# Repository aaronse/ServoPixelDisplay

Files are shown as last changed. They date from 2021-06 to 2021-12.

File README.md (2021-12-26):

  # Multiverse's Lowest LO-FI Wood Pixel Display—Arduino Art 
  Lowest LOFI display in the known 10 hyper dimensional multiverse, that I've seen.  Wood based tech art.
  
  Watch https://www.youtube.com/watch?v=4f1J5LzRdIo for usage and build information.
  
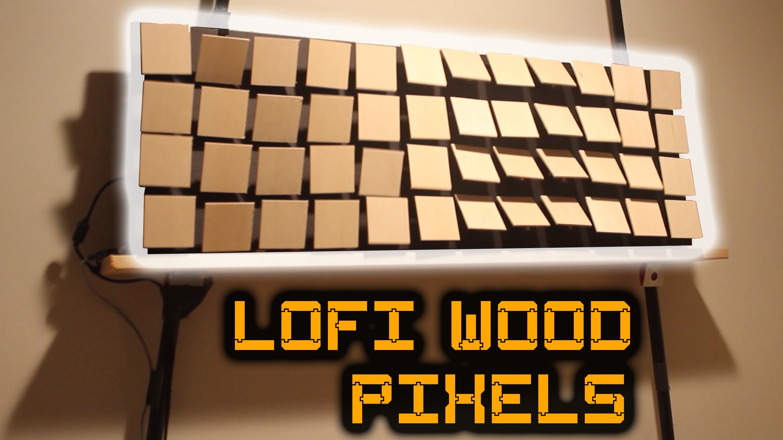
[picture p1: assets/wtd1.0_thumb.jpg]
  
  
  This code was written to power the WTD 1.0 (Wood Tile Display) project 
  created while participating in Mark Rober's 
  https://monthly.com/mark-rober-engineering course.

  Cheers!
  
  aaron (Aza's Built to Code)

  ## Code
  [src/wtd_1/wtd_1.ino](src/wtd_1/wtd_1.ino)
  - Displays Wave pattern by default.  Pause/Resume by sending "1" via Serial Monitor.  Edit _mode to change default start mode.

  ## Model .STL file
  [SG90 Arm Angle 10.stl](models/SG90%20Arm%20Angle%2010.stl)
  <!-- https://github.com/aaronse/ServoPixelDisplay/blob/main/models/SG90%20Arm%20Angle%2010.stl -->
  
  ## Build

  Backside view of the rats nest wiring.  Note the WAGO connectors, 16awg for power, and skinny wiring for data lines.  v1.0 was (under) powered by a 5v 5amp Alitov power adapter.
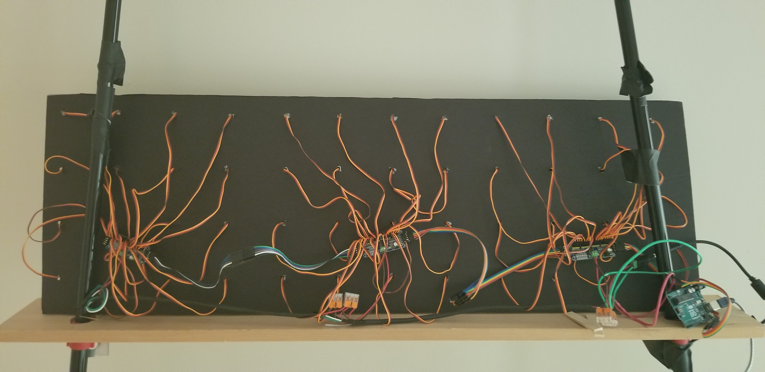
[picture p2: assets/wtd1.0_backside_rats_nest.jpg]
WTD v1.0 backside rats nest
  

  ## Related work/projects
  
- https://github.com/julienp17/WaveMirror (reco by https://github.com/scorto)
- "Reflection" - Making of an art installation for Prague Signal Festival, https://www.youtube.com/watch?v=jHo4l41cz8s

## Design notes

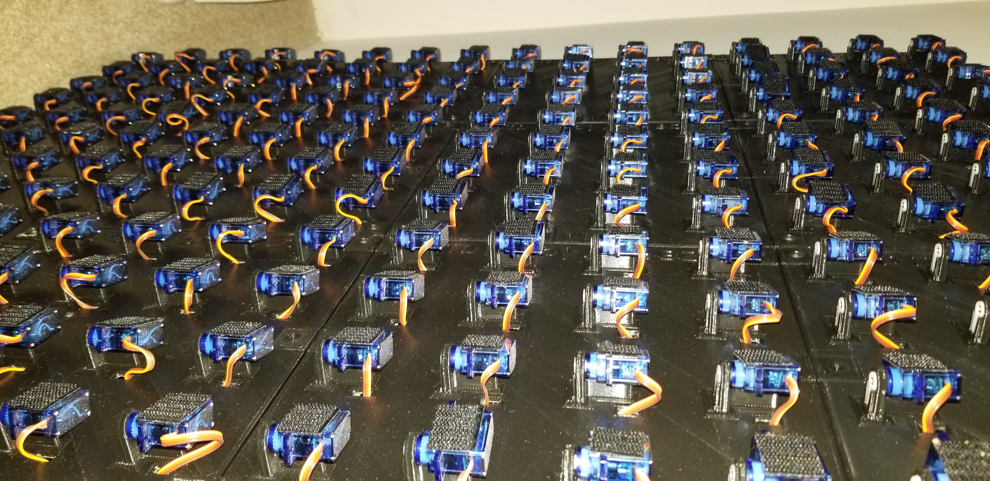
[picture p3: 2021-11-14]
assets/wtd2.0_servos_mounted.jpg

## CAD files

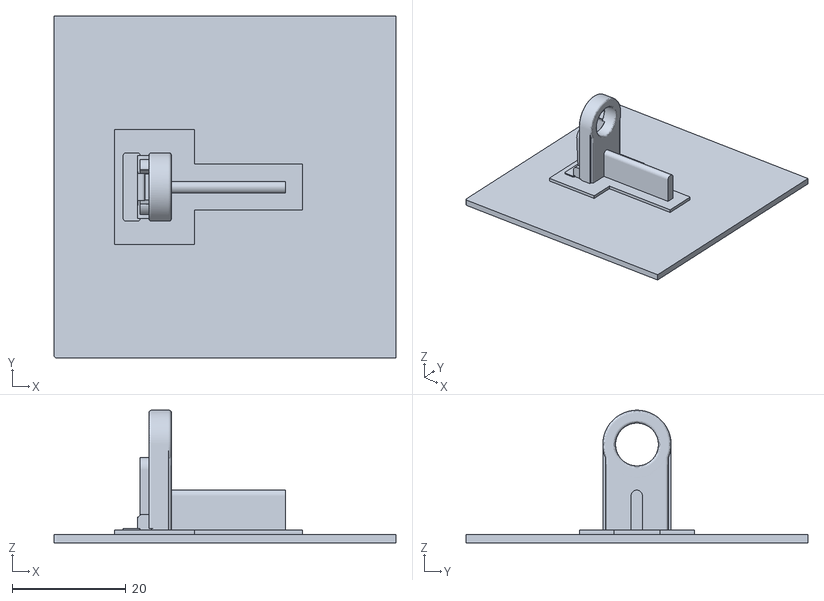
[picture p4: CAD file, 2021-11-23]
models/WTD_Tile_v2.1_60mm.stl
60.0 x 60.0 x 23.3

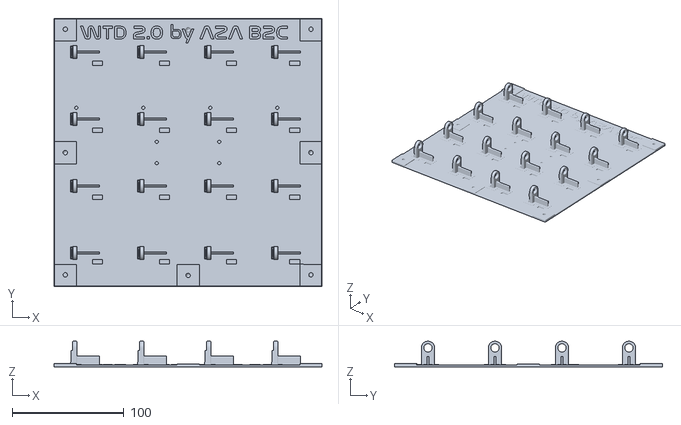
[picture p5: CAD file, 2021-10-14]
models/WTD_Tile_v2.7_4x4.stl
240.0 x 240.0 x 23.0

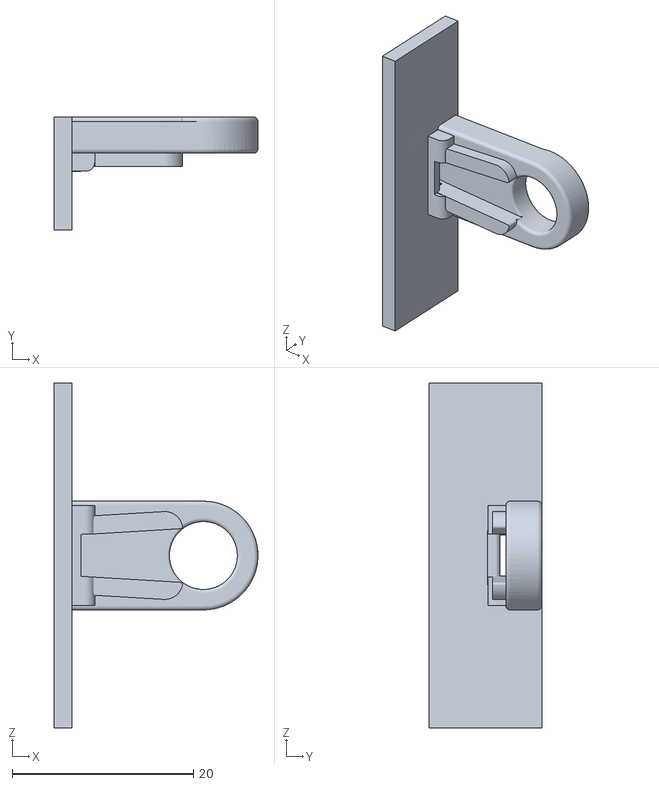
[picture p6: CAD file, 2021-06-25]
models/SG90 Arm Angle 10.stl
22.5 x 12.5 x 38.1

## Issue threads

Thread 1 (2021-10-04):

Hey this is Juan Sebastian from the YouTube comment. My partner and I are working on our senior capstone project that follows the same path as yours.

TigerKIN3, 2021-10-04:
We have our concerns about power draw due to us planning to use 320 servos. We are also concerned about the wire gauge for that many servos. There are more but we haven't explored them enough.

aaronse, 2021-10-04:
Hello @TigerKIN3, 320 servos, wow!   Haven't built anything that large, would love to hear from folks that have.  I know less about hardware/electrical than software.  Personally, would plan for 150ma per servo, but would expect steady state (servo not moving) will draw much less than 150ma.  So, 150ma X 320 = 48amp, I'd plan for 80% or less of supply capacity.  So 5v 60amp would be what I'd get, infact, https://www.amazon.com/gp/product/B00IWC2RLS is what I ended up buying for WTD 2.0.  Used mix of flexible silicone 14-18AWG wire (depending on expected current) for trunks going from power supply to each Pca9685 board.

TigerKIN3, 2021-10-04:
Thank you @aaronse for the insightful information. We plan on using SG-90 servos like the ones in your video. Is there any servos problems that we should look out for in our construction.

aaronse, 2021-10-04:
You're welcome.  Been pretty lucky with https://amzn.to/3oxd1E5, so far...  ~5% arrived broken/not-working.  Initially over ordered by 10% expecting some Duds, returning ones I didn't need...  Experienced some jittering/twitching by the servos when they're supposed to be steady, could be caused by bad/wrong wiring on my part.

*IF* you run into jitter issues, something to consider is using the PCA9685's OE pin to cut power via your code for moments when you're not expecting the Servo's to move.  Didn't do this, feel free to share pull request if you encounter and fix this issue :-)

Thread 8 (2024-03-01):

Servo Motors move jerkily, how to improve the movement?

aaronse, 2024-03-01:
hi, I tried your program but the servomotors move jerkily, what can I do to improve the movement of the motors? Furthermore, I would like to slow down the speed of the servomotors, what can I do?

_Originally posted by @Salvolongo in https://github.com/aaronse/ServoPixelDisplay/discussions/2#discussioncomment-8648347_

aaronse, 2024-03-01:
Hello @Salvolongo!

The issue you're encountering with jerky movements in SG90 9g servo motors, while using PCA9685 PWM servo controller boards, can stem from several factors. Here are common reasons and solutions to improve the movement of the motors:

### 1. Power Supply Issues
- **Problem:** Inadequate or unstable power supply can cause jerky movements. SG90 servos typically operate at 4.8V to 6V, and their performance can significantly degrade if the voltage drops below this range or if the power supply cannot provide sufficient current.
- **Solution:** Ensure your power supply can deliver consistent voltage within the servo's operating range and can handle the current draw of all servos under load. Using a dedicated, high-quality power supply might resolve the issue.

### 2. Signal Interference or Noise
- **Problem:** Electrical noise or interference in the PWM signal from the PCA9685 to the servos can cause erratic movements.
- **Solution:** Use shorter cables to reduce the chance of interference, and consider adding ferrite beads or capacitors to filter out noise. Ensuring solid, clean connections can also help.

### 3. PWM Frequency Mismatch
- **Problem:** The PCA9685 allows you to set the PWM frequency, and if this frequency doesn't match what the servos expect, it can result in jerky movements.
- **Solution:** The SG90 servos typically expect a 50Hz PWM signal. Ensure the PCA9685 is configured to output at this frequency.

### 4. Mechanical Load and Binding
- **Problem:** Mechanical resistance or binding in the servo gears or in the mechanism the servos are driving can cause jerky movements.
- **Solution:** Check for any mechanical issues that might be causing resistance to the servo's movement. Lubricate gears if necessary and ensure that the load on the servo is within its capabilities.

### 5. Software Issues
- **Problem:** The way the PWM signals are being modulated in your code can lead to jerky movements if not done smoothly.
- **Solution:** Implement smoother transitions in your control algorithm. For example, instead of jumping from one position to another instantly, gradually increase the PWM signal to create a smoother motion.

### 6. Servo Quality or Damage
- **Problem:** SG90 servos are inexpensive and can vary in quality. Sometimes, internal damage or wear can cause poor performance.
- **Solution:** Test with another servo to see if the problem persists. If a replacement servo works better, the issue might be with the original servo's quality or condition.

### 7. Calibration Issues
- **Problem:** If the PCA9685's PWM signal doesn't match the servo's expected pulse width for its range of motion, it can cause erratic behavior.
- **Solution:** Calibrate your system by adjusting the PWM signal's pulse width to ensure it aligns with the servo's specifications for minimum and maximum positions.

### Additional Tips:
- **Use External Power:** For multiple servos, it's often recommended to power the servos separately from the logic board to prevent voltage drops and interference.
- **Check for Overloading:** Ensure that the servos are not being overloaded beyond their torque capacity, as this can also cause jerky movements.
- **Update Firmware/Software:** Make sure that the firmware on the PCA9685 and your control software are up to date to benefit from any bug fixes or improvements.

By systematically addressing these potential issues, you should be able to identify and mitigate the cause of the jerky movements in your SG90 servo motors.

Can slow down speed of the servomotors by changing the delay(10); which means wait 10 milliseconds, to a much larger number between updates, maybe try 100 milliseconds, something to experiment with.

https://github.com/aaronse/ServoPixelDisplay/blob/5fcea9af71efd5064f86ff9575d3d690f0de3f88/src/wtd_1/wtd_1.ino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

Hope that helps.  Cheers!

aaronse, 2024-03-01:
Closing this as an issue, and following up in the Q&A /Discussion area instead https://github.com/aaronse/ServoPixelDisplay/discussions/9

Salvolongo, 2024-03-02:
I tried bringing the delay to 100, the motors move slower but they move jerkily and have a bad effect, I would like to make the movements more fluid, the motors are not attached to anything so they are not overloaded

Closed 2024-03-01.

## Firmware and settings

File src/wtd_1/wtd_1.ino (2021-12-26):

/******************************************************************************

  "Multiverse's Lowest LO-FI Wood Pixel Display—Arduino Art" (Version 1.0)
  https://www.youtube.com/watch?v=4f1J5LzRdIo

  This code was written to power the WTD 1.0 (Wood Tile Display) project 
  created while participating in Mark Rober's 
  https://monthly.com/mark-rober-engineering course.

  The code, originally written in a day, started out based on an AdaFruit 
  sample, and uses Adafruit's library for PCA9685 based 16-channel PWM & Servo 
  drivers.  Consider buying drivers and other hardware goodies from the 
  Adafruit shop @ http://www.adafruit.com/products/815
  
  Adafruit invests time and resources providing this open source code, 
  please support Adafruit and open-source hardware by purchasing 
  products from Adafruit!

  Cheers!

  aaron (Aza's Built to Code)
******************************************************************************/

#include <Wire.h>
#include <Adafruit_PWMServoDriver.h>

// Animation modes
#define MODE_NONE 0
#define MODE_WAVE 1
#define MODE_INVERT 2

// NOTE: EDIT FOR YOUR BUILD.
int _mode = MODE_WAVE; // Starts with WAVE mode, edit to MODE_NONE if you don't want WTD to be move until prompted.

// NOTE: EDIT FOR YOUR BUILD
// - Should be set to number of PCA9685 drivers used. Current code assumes each 
//   driver is connected to 16 servos. So, should define as total servo count 
//   divided by 16, e.g. 9 for 144 == 12x12 servo build.
#define DRIVER_COUNT 3

// NOTE: EDIT FOR YOUR BUILD
// - Short: Servo driver I2C Address definitions.
// - Long: pwmDrivers[] defines a list of PCA9685 servo drivers. Each PCA9685 
//   driver has a unique I2C address, starting at 0x40 (you solder during build
//   assembly). The code uses this list to figure out which PCA9685 servo 
//   driver is connected to a given servo, enabling the code to send commands 
//   to a specific driver. So, for example, with a 144 servo build, 9 entries 
//   would need to be defined, each entry with a unique I2C address based on
//   what was soldered during WTD assembly. See "Assumptions:" content to 
//   understand tileset layout and wiring sequence assumed by the code.
Adafruit_PWMServoDriver pwmDrivers[] =
{
   Adafruit_PWMServoDriver(0x40), // Ensure the address sequence here matches your Build's tileset layout.  Left to right, row by row, starting from top row.
   Adafruit_PWMServoDriver(0x41),
   Adafruit_PWMServoDriver(0x42)
};

// NOTE: EDIT FOR YOUR BUILD
#define CANVAS_WIDTH 12   // Servos per row, think of as display pixel width.
#define CANVAS_HEIGHT 4   // Number of rows, think of as display pixel height. 

// NOTE: *MAYBE* EDIT FOR YOUR BUILD, if you're not using Miuzei SG90 servos.
// - Depending on your servo make, the pulse width min and max may vary, you 
//   want these to be as small/large as possible without hitting the hard stop
//   for max range. You'll have to tweak them as necessary to match the servos
//   you have!  The following worked for my Miuzei SG90 servos.
#define SERVOMIN  150 // - This is the 'minimum' pulse length count (out of 4096)
#define SERVOMAX  600 // - This is the 'maximum' pulse length count (out of 4096)
#define SERVO_FREQ 60 // - Analog servos run at ~60 Hz updates.  Try 50 (original 
                      //   sample value) if your servos have a seizure using 60.

#define PIXEL_COUNT CANVAS_WIDTH * CANVAS_HEIGHT
#define TILESET_WIDTH 4   
#define TILESET_HEIGHT 4

#define MIN_SERVO_ANGLE 0
#define MAX_SERVO_ANGLE 60

// Menu variable to pick each menu item(or display the menu)
int _menu = -1;

// Flag indicating whether to move/animate
bool _isActive = true;

float _pixels[PIXEL_COUNT];
bool _pixelsDirty = true;
int _currentPixelIndex = 0;
unsigned long _lastChangeMs = 0;
unsigned long _invertWaitIntervalMs = 10;
unsigned long _waveWaitIntervalMs = 10;

void drawFill(int color);
void processMenu();
void processPixels();
void woodTilePanel_loop();


void setup() {
  Serial.begin(9600);
  Serial.println("setup");

  for (int i = 0; i < DRIVER_COUNT; i++) {
    pwmDrivers[i].begin();

  /* From AdaFruit sample code:
   * "In theory the internal oscillator (clock) is 25MHz but it really isn't
   * that precise. You can 'calibrate' this by tweaking this number until
   * you get the PWM update frequency you're expecting!
   * The int.osc. for the PCA9685 chip is a range between about 23-27MHz and
   * is used for calculating things like writeMicroseconds()
   * Analog servos run at ~50 Hz updates, It is importaint to use an
   * oscilloscope in setting the int.osc frequency for the I2C PCA9685 chip.
   * 1) Attach the oscilloscope to one of the PWM signal pins and ground on
   *    the I2C PCA9685 chip you are setting the value for.
   * 2) Adjust setOscillatorFrequency() until the PWM update frequency is the
   *    expected value (50Hz for most ESCs)
   * Setting the value here is specific to each individual I2C PCA9685 chip and
   * affects the calculations for the PWM update frequency. 
   * Failure to correctly set the int.osc value will cause unexpected PWM results"
   */
    pwmDrivers[i].setOscillatorFrequency(27000000);
    pwmDrivers[i].setPWMFreq(SERVO_FREQ);

    delay(10);
  }
}


// Set pulse length in seconds. e.g. setServoPulse(0, 0.001) is a ~1 ms pulse width. It's not precise!
void setServoPulse(uint8_t driverIndex, uint8_t n, double pulse) {

  double pulselength;
  
  pulselength = 1000000;        // 1,000,000 us per second
  pulselength /= SERVO_FREQ;    // Analog servos run at ~60 Hz updates
  Serial.print(pulselength); 
  pulselength /= 4096;          // 12 bits of resolution
  Serial.print(pulselength); 
  pulse *= 1000000;             // convert input seconds to us
  pulse /= pulselength;
  Serial.println(pulse);

  pwmDrivers[driverIndex].setPWM(n, 0, pulse);
}


void loop() {

  processMenu();

  processPixels();

  woodTilePanel_loop();

  delay(10);
}


void processPixels() {

  // Bail if inactive
  if (!_isActive) return;

  // Invert mode and time to invert next pixel?
  if (_mode == MODE_INVERT &&  millis() > _lastChangeMs + _invertWaitIntervalMs) {
    _lastChangeMs = millis();

    if (_currentPixelIndex >= PIXEL_COUNT) {
      _currentPixelIndex = 0;
    }

    float newColor = 100 - _pixels[_currentPixelIndex];
    _pixels[_currentPixelIndex] = newColor;
    _pixelsDirty = true;
    _currentPixelIndex++;
  }

  if (_mode == MODE_WAVE && millis() > _lastChangeMs + _waveWaitIntervalMs) {

    Serial.print("processPixels MODE_WAVE");

    if (_currentPixelIndex >= CANVAS_WIDTH) {
      _currentPixelIndex = 0;
    }

    for(int x = 0; x < CANVAS_WIDTH; x++) {
      
      _lastChangeMs = millis();
      _pixelsDirty = true;

      // Compute Degree phase for current column, offset by _currentPixelIndex.  Stretch full wave 
      // to span width of the canvas.
      long waveLength = CANVAS_WIDTH;
      float phaseRatio  = ((1.0 * ((x + _currentPixelIndex) % waveLength)) / waveLength);
      float phaseAngleDeg = (int)(phaseRatio * 360.0) ;//% 360;
      // TODO:P0 Implement enabling configurable phase delta and overall wave length to span longer than canvas width.

      // Convert column's phase angle to radians so we can calculate sin wave height.
      float phaseAngleRad = phaseAngleDeg * 0.01745329252;
      float amplitude = sin(phaseAngleRad);

      // Map to brightness scale (0 - 100)
      float pixelColor = (amplitude + 1.0) * 50.0;

      if (x == 0) {
        Serial.print("phaseRatio: ");
        Serial.print(phaseRatio);
        Serial.print(", phaseAngleDeg: ");
        Serial.print(phaseAngleDeg);
        Serial.print(", phaseAngleRad: ");
        Serial.print(phaseAngleRad);
        Serial.print(", amplitude: ");
        Serial.print(amplitude);
        Serial.print(", pixelColor: ");
        Serial.print(pixelColor);
        Serial.println();
      }

      for(int y = 0; y < CANVAS_HEIGHT; y++) {
        _pixels[(CANVAS_WIDTH * y) + x] = pixelColor;
      }
    }

    _currentPixelIndex++;
  }
}

void woodTilePanel_loop() {

  // Bail if inactive
  if (!_isActive) {
    return;
  } 

  // TODO:P2 Bail if !_pixelsDirty optimization.
  
  // Enumerate through each pixel.
  for (int row = 0; row < CANVAS_HEIGHT; row++) {
    for (int col = 0; col < CANVAS_WIDTH; col++) {

      float pixelBrightness = _pixels[row * CANVAS_WIDTH + col];

      // Ensure brightness within bounds
      // TODO:P0 ASSERT/WARN about unexpected values, fix upstream bug(s).
      if (pixelBrightness < 0.0 ) pixelBrightness = 0.0;
      if (pixelBrightness > 100) pixelBrightness = 100;

      // Map pixel brightness to servo angle in degrees
      long servoAngle = map(pixelBrightness, 0, 100, MIN_SERVO_ANGLE, MAX_SERVO_ANGLE);

      // ENSURE angle value is bounded.  Also, WARN about unexpected values, fix upstream bug(s).
      if (servoAngle > MAX_SERVO_ANGLE) {
        Serial.print("WARN: Ignoring unexpected large angle, servoAngle=");
        Serial.println(servoAngle);

        servoAngle = MAX_SERVO_ANGLE;
      }

      if (servoAngle < MIN_SERVO_ANGLE) {
        Serial.print("WARN: Ignoring unexpected small angle, servoAngle=");
        Serial.println(servoAngle);

        servoAngle = MIN_SERVO_ANGLE;
      }

      // Map servo angle to pulse length
      long pulseLength = map(servoAngle, 0, 180, SERVOMIN, SERVOMAX);

      // Lookup PWM Driver index for current pixel
      // TODO:P1 Implement Canvas-TileSet map when PWM drivers not in order
      // Assumptions:
      // - TileSets are layed out from top left, row by row.
      int pwmIndex = 
        ((CANVAS_WIDTH / TILESET_WIDTH) * (row / TILESET_HEIGHT)) + // Compute Row tileset offset
        (col / TILESET_WIDTH);                                      // Compute Col tileset

      // Lookup pixel servo
      Adafruit_PWMServoDriver pwmDriver = pwmDrivers[pwmIndex];

      // Assumptions:
      // - Tile wiring is layed out column by colum, from top to bottom within a column.
      //    0  4  8 12
      //    1  5  9 13
      //    2  6 10 14
      //    3  7 11 15
      int servoNum =
        (col % TILESET_WIDTH) * TILESET_HEIGHT + (row % TILESET_HEIGHT);
      
      // Set servo PWM
      pwmDriver.setPWM(servoNum, 0, pulseLength);
    }
  }

  _pixelsDirty = false;
}


void processMenu()
{
  // Display menu if just started of finished some other action.
  if (_menu == -1) {
    
    // Print menu to serial port (based on Mark Rober's example)
    Serial.println("Select an option:");
    Serial.println("-----------------");
    Serial.println((_isActive) ? "1) Stop!!" : "1) Go...");
    Serial.println("2) Set Servos to Min");
    Serial.println("3) Set Servos to Mid");
    Serial.println("4) Set Servos to Max");
    Serial.println("5) Wave Mode");
    Serial.println("6) Invert Mode");
    Serial.flush();

    _menu = 0;
  }

  // Check if we have input data on the serial port to process?
  if (Serial.available()) {
    _menu = Serial.parseInt(); // Takes the Serial input and looks for an integer
    
    Serial.print(">");
    Serial.println(_menu);
    Serial.flush();
  }

  if (_menu == 1) {
    _isActive = !_isActive;
  }  
  else if (_menu == 2) {
    _isActive = true;
    _mode = MODE_NONE;
    drawFill(0);
  }
  else if (_menu == 3) {
    _isActive = true;
    _mode = MODE_NONE;
    drawFill(50);
  }
  else if (_menu == 4) {
    _isActive = true;
    _mode = MODE_NONE;
    drawFill(100);
  }
  else if (_menu == 5) {
    _isActive = true;
    _mode = MODE_WAVE;
    Serial.println("MODE_WAVE selected");

    _currentPixelIndex =  0;  // Use to track sin wave by column
  }  
  else if (_menu == 6) {
    _isActive = true;
    _mode = MODE_INVERT;
    Serial.println("MODE_INVERT selected");
    
    _currentPixelIndex =  0; // Use to tracke pixel being inverted
  }  
  else if (_menu > 0) {
    Serial.print("'");
    Serial.print(_menu);
    Serial.print("' is not a valid menu option.  Try harder.");
    Serial.println();
  }

  // Reset menu state to display prompt on next iteration
  if (_menu > 0) {
    _menu = -1;
  }
}


void drawFill(int color)
{
  for (int i = 0; i < CANVAS_WIDTH * CANVAS_HEIGHT; i++) {
    _pixels[i] = color;
  }
  _pixelsDirty = true;
}

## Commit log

2021-06-25 Add servo arm
    [SG90 Arm Angle 10.stl]
2021-09-24 Added photo showing horrific view of the backside wiring rats nest.
2021-10-14 WTD Tile v2.7 4x4
    [WTD_Tile_v2.7_4x4.stl]
2021-11-23 Add files via upload
    Print tile arms 45 deg around Z axis, so initial layer lines are vertical or horizontal, this will help maximize pixel contrast range.
    [WTD_Tile_v2.1_60mm.stl]
